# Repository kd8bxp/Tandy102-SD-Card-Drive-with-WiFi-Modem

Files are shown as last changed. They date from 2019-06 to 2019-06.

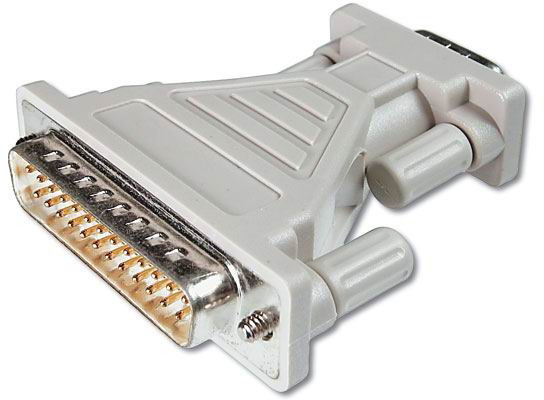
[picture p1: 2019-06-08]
9-to-25-Pin-Serial-Adapter-Pinout.jpg

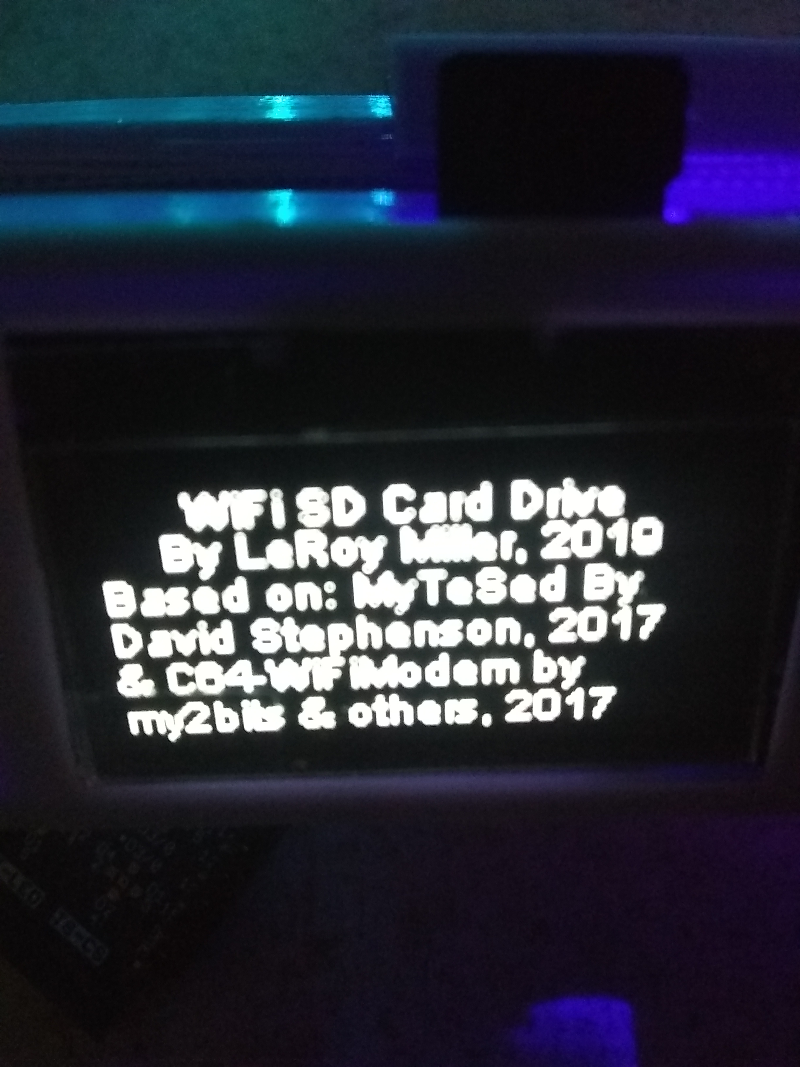
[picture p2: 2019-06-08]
Pictures/IMG_20190527_114814271.jpg

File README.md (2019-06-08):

# Tandy 102 WiFi SD Card

This could not have been made without the following projects:  
 MyTeSed: T100 SD Card Reader for the Arduino Nano and SD Card Reader. By David  
Stephenson 10-11-2017.  
https://www.zx81keyboardadventure.com/2017/08/model-100-micro-sd-card-reader-mytesed.html  
https://youtu.be/7AtsHzl9WMc  
This project "emulates" a PDD - I use emulate loosely. It does let you load and save programs to/from the Tandy 102. It saves the programs to the SD card.  

The next project is the C64-WiFiModem project that was based on serveral other projects.  
The version I used can be found here:  https://github.com/DrZingo/c64-wifimodem  
   C64-WiFiModem - (c) 2017 my2bits <markus at borgelin.org>  
See the credit.h file for more information about this project.  
The basics of it, it gives the ability of vintage machines to connect to the web,  
and is really good for telneting to online BBS systems.  
AT? for help.  

These two projects were ported over to the ESP32, which wasn't that hard to do, a few changes to the base code were needed.  
One thing that stopped working is the ability to telnet into the vintage machine (so for now, you can't run that BBS on your Tandy 102).  

The final project that made all this come together is FTP Server based on FTPServerSample & esp8266FTPServer by nailbuster Oct 2017
https://github.com/nailbuster/esp8266FTPServer
Modified by robo8080 for SD card use 2017 https://github.com/robo8080/ESP32_FTPServer_SD  

The only thing I did was to add some feedback displayed on the OLED, otherwise that project already worked on the ESP32  
 
## Things To Do

After I got all the code working, I just merged the 3 base codes together with a menu system that I wrote, because of this:  
There is some redundant code, and future versions I want to clean it up as much as  
I can.  
Telnet Server doesn't work, I'd like to figure out how to get that working.  
And maybe add code in all the bases to switch from one mode to the next easy. (Maybe)  
The SD card reader needs to have the leading "/" included with file names.  
I'd like to have software check for this an add it if needed.  
Currently, you need it otherwise it doesn't work - there is no error printed so you don't know it doesn't work.  
Interestingly enought you don't need the leading "/" when using FTP, but you do need a good FTP client, at least I did.  

## Hardware Used

1) TTGO T-eight board - this board has an ESP32, on board SD card reader/writer, 3 switch/button toggle, OLED, and lipo charger (I'm not using a battery).  
2) MAX232 board, the board I am using has a 9pin female connector, and only has RX/TX broken out. 5v and Ground  
3) 9 pin to 25 pin serial adaptor for the Tandy, and maybe/probably a 9 pin serial gender changer.  
4) (Optional) 3D printed case and stand.  

Hookup is fairly easy and straight forward, connect the Max232 VCC to 5v pin, GND to GND, TX to TX, and RX to RX, load the sketch on the board, and test.  
IF it doesn't work, try reversing the TX and RX pins (in other words, connect TX to RX, and RX to TX).  

## Usage

My Tandy 102 didn't like an speed but 300 baud, I know slow. So you need to have your com port set for 300 baud. (38N1D works)  
For the SD card drive, in the terminal type "help" without the quotes. You'll get a
small amount of "help" - It's not very good, but might be enough to give you some help.  

For the C64-WiFiModem you can use "AT?" in command mode, and you'll get some help.  

You need a good FTP Client when using the FTP mode.  
(You don't need to remove the SD card, and can copy and move files on the SD card over FTP) - It's nice!   

To get back to the menu, use the center button.  The ESP32 will reset and you'll get the menu again.  

## Demo Video

coming soon....  

## Contributing

1. Fork it!
2. Create your feature branch: `git checkout -b my-new-feature`
3. Commit your changes: `git commit -am 'Add some feature'`
4. Push to the branch: `git push origin my-new-feature`
5. Submit a pull request

## Support Me

If you find this or any of my projects useful or enjoyable please support me.  
Anything I do get goes to buy more parts and make more/better projects.  
https://www.patreon.com/kd8bxp  
https://ko-fi.com/lfmiller  
https://www.paypal.me/KD8BXP  

## Other Projects

https://www.youtube.com/channel/UCP6Vh4hfyJF288MTaRAF36w  
https://kd8bxp.blogspot.com/  

## Credits

Copyright (c) 2019 LeRoy Miller

## License

This program is free software: you can redistribute it and/or modify
    it under the terms of the GNU General Public License as published by
    the Free Software Foundation, either version 3 of the License, or
    (at your option) any later version.

    This program is distributed in the hope that it will be useful,
    but WITHOUT ANY WARRANTY; without even the implied warranty of
    MERCHANTABILITY or FITNESS FOR A PARTICULAR PURPOSE.  See the
    GNU General Public License for more details.

    You should have received a copy of the GNU General Public License
    along with this program.  If not, see <http://www.gnu.org/licenses>

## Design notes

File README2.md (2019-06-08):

## Robot Code

Included is one example of controlling a robot over WiFi with the Tandy 102.  
arexx_d1_mini_telnet_controlled_robot_test_code - this is basicly a telnet server running on a D1 Mini (ESP8266) board, connected to the D1 Mini Motor Shield, using a general/genic 2 wheeled robot plateform.  
In the Tandy102_Robot_Code directory, you'll find the basic program that the Tandy 102 runs - it's pretty simple.  
Turn the SD WiFi card device on, selected the WiFi Modem, run the basic program, which should hit the enter key, connect to the D1 Mini Access Point, and make the robot move forward for a short time, and stop.  
It's just one example of what can be done.

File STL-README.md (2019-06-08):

## Credit where credit is due

The stand was created by Denny77 Dec 2017, https://www.thingiverse.com/thing:2689401  
I made it larger, but otherwise it's his design.  

The lid is my own creation, I'm not very good at making lids yet, but this one works.  

The case is a remix of my TTGO Teight case https://www.thingiverse.com/thing:3634368  
I made it taller, then because the MAX232 board is slightly larger, I stuck a larger box on top (or bottom depending on how you look at it.) This give a interesting two layer effect.  
I ended up cutting the openning for the 9 Pin port a little bit to get the board to fit a little better, and the 9 pin gender changer is used to help hold it in place.  

I took a guess on the size the stand should be, and happy accident it fit almost perfect (honestly it's just slightly too big, but that makes it easy to slide the case in and out).  

So what wasn't planned, turned out to be a good fit for the case.

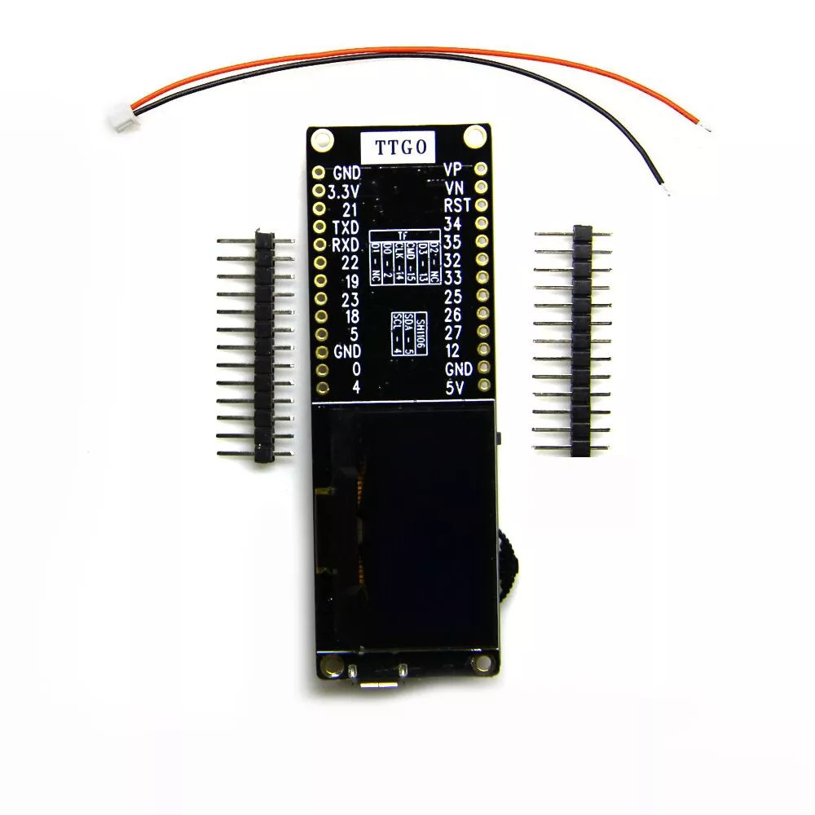
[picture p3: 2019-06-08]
ttgo-teight.jpg

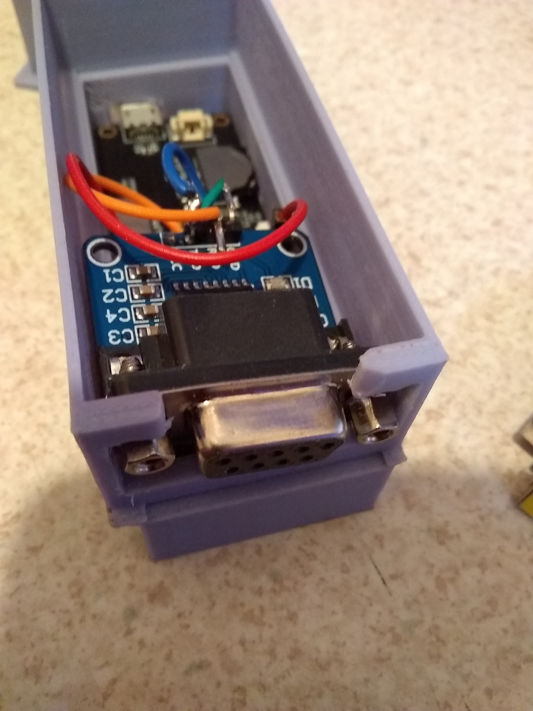
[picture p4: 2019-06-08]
Pictures/2019-06-08 01.26.06.jpg

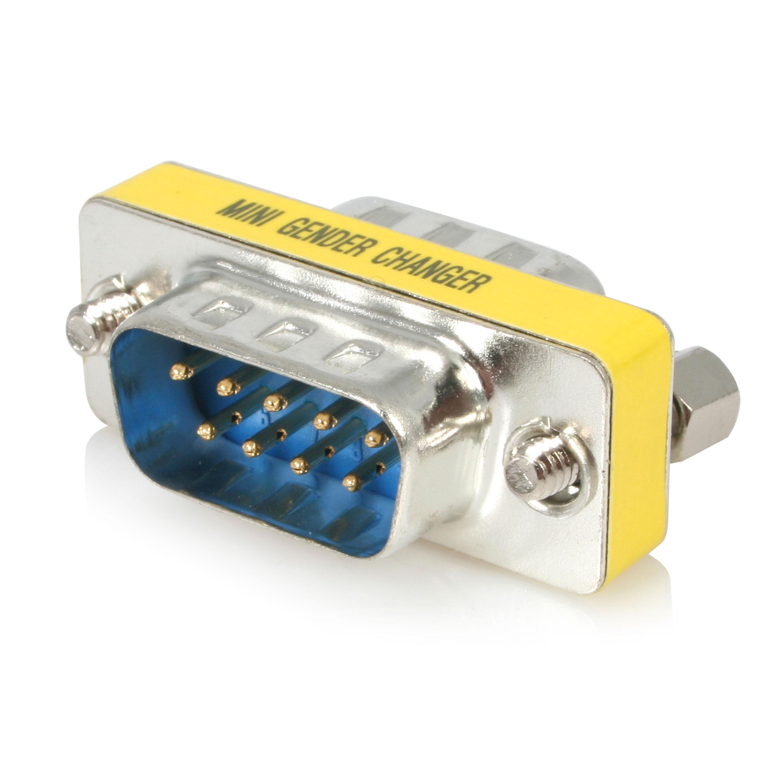
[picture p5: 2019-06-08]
6ada19d5-7ea9-411c-b23a-e80710b06e3e.jpg

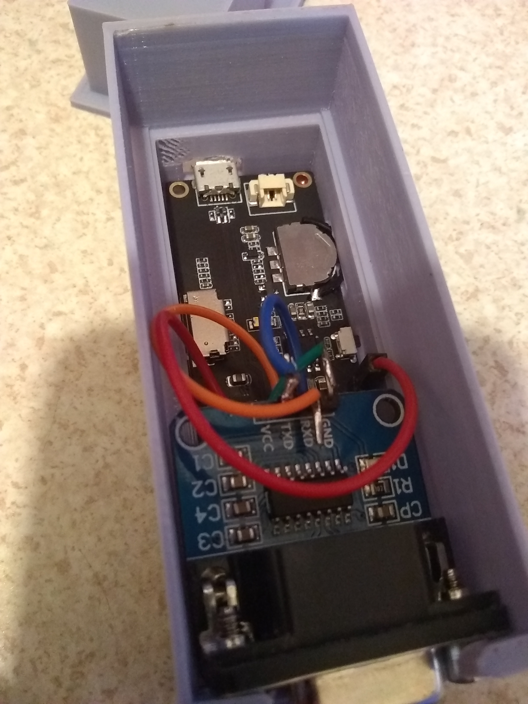
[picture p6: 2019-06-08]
Pictures/2019-06-08 01.26.12.jpg

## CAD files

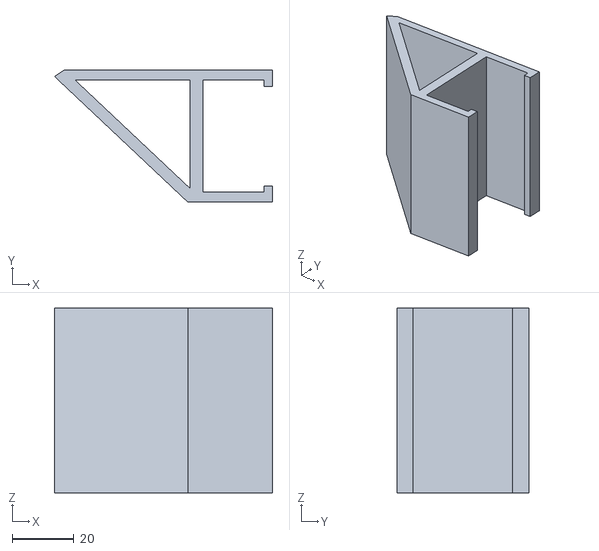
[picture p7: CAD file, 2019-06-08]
STL_Files/stand.stl
70.8 x 43.0 x 60.0

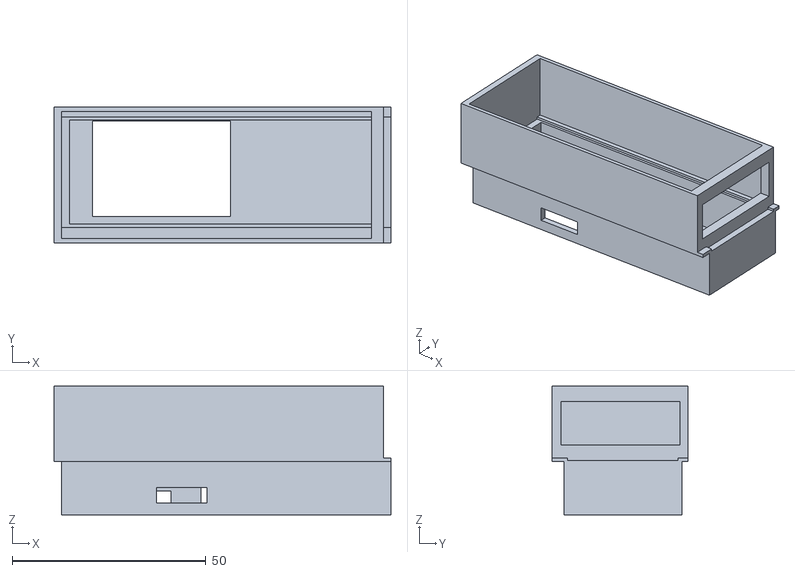
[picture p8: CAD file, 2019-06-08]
STL_Files/case.stl
87.0 x 35.0 x 33.2

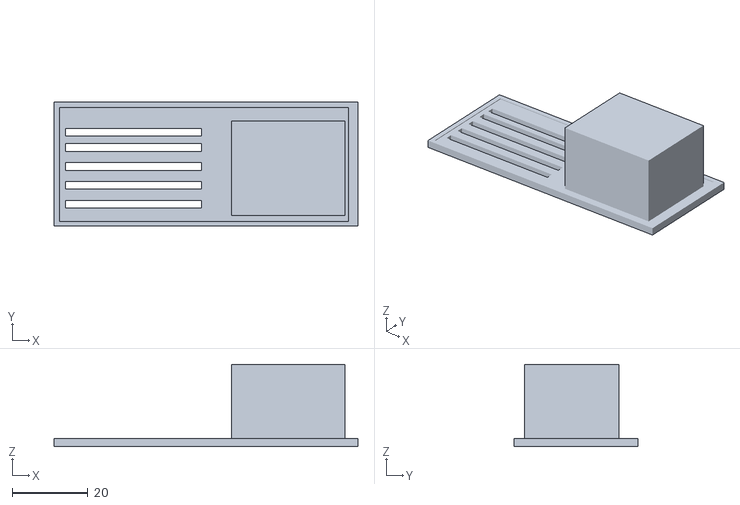
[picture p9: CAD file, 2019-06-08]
STL_Files/Lid.stl
80.2 x 32.7 x 21.8

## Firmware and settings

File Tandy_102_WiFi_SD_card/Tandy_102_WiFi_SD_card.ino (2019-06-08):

/*
 * Tandy 102 WiFi SD card drive
 * Ported to ESP32 by LeRoy Miller May 2019
 * see credit.h tab for additional information and credit to other projects.
 */

#include <SPI.h>
#include <SD.h>
#include "XModem.h" // Xmodem Only working with the NEC PC-8401 at the moment... To be fixed at some point.
#include <Wire.h>  // Only needed for Arduino 1.6.5 and earlier
#include "SH1106Wire.h" // alias for `#include "SSD1306Wire.h"`
#include "SH1106.h" //https://github.com/ThingPulse/esp8266-oled-ssd1306
#include <WiFi.h>
#include <WebServer.h>
#include <EEPROM.h>
#include <ESPmDNS.h>
#include <HTTPClient.h>
#include "defines.h"
#include <WiFiClient.h>
#include "ESP32FtpServer.h"

const char* FTPssid = "homeinternet"; //for now this is how we are going to connect using the FTP server
const char* FTPpassword = "trixie4me"; //I want to change this to make the code more lean.

FtpServer ftpSrv;   //set #define FTP_DEBUG in ESP32FtpServer.h to see ftp verbose on serial


SH1106 display(0x3c, 21, 22); 
WiFiClient tcpClient;
WiFiServer tcpServer(tcpServerPort);
WebServer webServer(80);
MDNSResponder mdns;


// **** Setup Constants ****

// Set default Baud Rate
// Settings on T100/T02/T200 for reference
// 1 = 75,   2 = 110,  3 = 300
// 4 = 600,  5 = 1200, 6 = 2400
// 7 = 4800, 8 = 9600, 9 = 19200
//const int BAUD_RATE=19200; // Tandy T100/T02/T200
//const int BAUD_RATE=9600; // NEC PC-8401
const int BAUD_RATE=300;

// Write out Delay
// Without Hardware flow control all writing to the T100 requires a delay
// This allows for fast saving and a normal loading speed
// This ends up reducing the T100 inbound baud rate to aprox 2400 from 19200
// Writing to the Screen in Telcom from SD requires 2*the OUT_DELAY
const byte OUT_DELAY=10;

// Commands issued to MyTeSeD
// LOAD:  Load directly from SD card into BASIC
// SAVE:  Save BASIC File directly to SD card
// KILL:  Delete file from SD card
// MOVE:  Rename File on SD card
// TCOPY: Copy from SD card to T100
// MCOPY: from T100 to SD
// ERR:   Return last Error code.
const String KEYWORDS[12] = {"LOAD","SAVE","FILES","KILL","HELP","DEL","DIR","COPY2R","COPY2D","CAT","XGET"};

// Set Serial Port Modes
// FREE:     Not busy
// DATA_IN:  Reading From T100
// DATA_OUT: Sending to T100
enum SerialStates {FREE, DATA_IN, DATA_OUT};

// Command Time Out: If no data from T100 after 15 seconds timeout on "SAVE" or "COPY2D"
const long TIMEOUT = 15000;

// Character Codes
// LF = Line Feed, CR = carriage return, EF = End of File
//enum CharCodes {LF = 10, CR = 13, EF = 26};

// ** LF & CR in XModem.h
// #define LF 0x0a
// #define CR 0x0d
#define EF 0x1a

// Error Codes
// Same values as T100
// SN = Syntax Error
// FF = File Not Found
// NM = Bad File Name
// CF = File Not Open (SD Card Not Found)
// Values could be sent to T100 for standard feed back with 'Error X' command
enum ErrorCodes {OK1 = 0, SN = 2 , FF = 52, NM = 55, CF = 58};

// Define Xmodem
XModem MyXmodem(&Serial, ModeXModem);

// **** Define Classes ****


// ***********************************************
// * Read / Writ SD Card send Serial out to T100 *
// ***********************************************
class SDCardDrive {

	private:

	// Variable for Saving Files
	File InFile; // File to save to

	ErrorCodes FileOut(String sFileName, byte bDelayOutLevel = 0){

		ErrorCodes eError = OK1;

		File OutFile;
		char cRead, cLast, cCount=1;
display.clear();
display.drawString(0,0,"Load...");
display.drawString(45,0,sFileName);
display.display();

		delay(250);
		OutFile = SD.open(sFileName);

		if(!OutFile){
			eError = FF;
		} else {
			// If bDelayOutLevel multiplier greater than 1
			// Then we are (willingly) writing to the LCD Screen
			// Add a LF for easy reading
			if(bDelayOutLevel > 1){
				Serial.write(CR);
				Serial.write(LF);
				delay(OUT_DELAY*(bDelayOutLevel*2));
			}

			while(OutFile.available()){
				if ( cCount == 2 ){
					delay(OUT_DELAY*bDelayOutLevel);
      				cCount = 1;
				}
				cCount++;
				cRead=OutFile.read();

				// If This is a BASIC file 'LOAD' ensures CR formating is used
				// Else outputs text as is
				if (cRead == LF && cLast != CR ){
					//Serial.write(cRead);
					Serial.write(CR);
        
				}

				Serial.write(cRead);
				cLast = cRead;
        
			}
		}

		OutFile.close();
    display.drawString(0,10,"Done!");
    display.display();
    
		// Only Write EOF of not writing to LCD
		if(bDelayOutLevel <= 1) Serial.write(EF);
		Serial.flush();

		return eError;

	}

	ErrorCodes FileOutXmodem(String sFileName){
		ErrorCodes eError = OK1;

		File OutFile;
		OutFile = SD.open(sFileName);

		// Make OLED displaySerial.println("Xmodem ready");
   display.clear();
   display.drawString(0,0,"Xmodem Ready.");
   display.display();
		if(!OutFile){
			eError = FF;
		} else {
			// Convert to sFileName to CPP style string
			// Make OLED displaySerial.println("Xmodem Sending");
     display.drawString(0,10,"Xmodem Sending.");
     display.display();
			//MyXmodem.sendFile(OutFile, sFileName.c_str());
      char buffer[15];
      sFileName.toCharArray(buffer, 15);
      MyXmodem.sendFile(OutFile, buffer);
      //MyXmodem.sendFile(OutFile, "testme.ba");
		}

		OutFile.close();
		return eError;
	}

	ErrorCodes FileInDelete(String sFileName, byte bDelayOutLevel = 0){
		ErrorCodes eError = OK1;
		if (SD.exists(sFileName)) {
			SD.remove(sFileName);
		} else {
			eError = FF;
		}
		// Assume for 'DEL' command we are writing to the LCD
		if(bDelayOutLevel > 0){
			Serial.write(CR);
			Serial.write(LF);
			delay(OUT_DELAY*(bDelayOutLevel*2));
		}
	}

	ErrorCodes FileInOpen(String sFileName){
		ErrorCodes eError = OK1;

		FileInDelete(sFileName);

		InFile = SD.open(sFileName, FILE_WRITE);

		if(!InFile){
			InFile.close();
			eError = FF;
		}

		return eError;
	}

	ErrorCodes FileDirOut(byte bDelayOutLevel = 4){

		ErrorCodes eError = OK1;

		File DirFile = SD.open("/");
		File FileInfo;

		if(!DirFile){
			eError = FF;
		} else {

			Serial.write(CR);
			Serial.write(LF);
			delay(OUT_DELAY*(bDelayOutLevel*4));

			//DirFile.rewindDirectory();

			while (true) {
				FileInfo = DirFile.openNextFile();

				if(!FileInfo){
					// no more files
					break;
				} else {
					//if (!FileInfo.isDirectory() && strlen(FileInfo.name()) < 10)  {

						// Only list files with a 2 character extension
						//if(FileInfo.name()[strlen(FileInfo.name())-3] == '.'){

							Serial.write(FileInfo.name());
              Serial.print("\t\t");
              Serial.println(FileInfo.size(), DEC);
							//Serial.write(FileInfo.name());
							delay(OUT_DELAY*bDelayOutLevel);

							/*for (byte iCount = strlen(FileInfo.name()) ; iCount < 10 ; iCount++){
								Serial.write(32);
								Serial.write(32);
							}*/

							delay(OUT_DELAY*bDelayOutLevel);

						//}

					//}
				}

				FileInfo.close();
			}

			Serial.write(CR);
			Serial.write(LF);
			delay(OUT_DELAY*bDelayOutLevel);

		}

		DirFile.close();
		//Serial.write(EF);
		Serial.flush();

		return eError;

	}


	// Return true if file is open
	boolean FileInWrite(char cInChar) {
  display.clear();
  display.drawString(0,0,"Saving....");
  display.display();
		if(cInChar != EF){
			Serial.print(cInChar);
			InFile.print(cInChar);
			return true;
		} else {
			InFile.close();
     display.drawString(0,10,"Done.");
     display.display();
			return false;
		}

	}


	public:

	// Open and read file
	// bBasicFile needs to be true if loading or saving a 'BASIC' file directly
	ErrorCodes ReadFile(String sFileName, byte bDelayOutLevel = 1){
		// Open SD card reader
		return FileOut(sFileName, bDelayOutLevel);
	}

	ErrorCodes ReadFilesDir(byte bDelayOutLevel = 8){
		// Open SD card reader
		return FileDirOut(bDelayOutLevel);
	}

	ErrorCodes FileXGet(String sFileName){
		return FileOutXmodem(sFileName);
	}

	ErrorCodes FileDelete(String sFileName,byte bDelayOutLevel = 1){
		// Open SD card reader
		return FileInDelete(sFileName, bDelayOutLevel);
	}

	ErrorCodes OpenFile(String sFileName){
		// Open SD card reader
		return FileInOpen(sFileName);
	}

	boolean OutFile(char cInChar){
		return FileInWrite(cInChar);
	}

	void OutFileTimeOut(){
    display.clear();
    display.drawString(0,0,"Timeout: File Closed");
    display.display();
		InFile.close();
	}
 
};


// *************************************
// * User Command from Serial in / out *
// *************************************
class SerialInOut {

	private:

	ErrorCodes eLastError;

	SDCardDrive InOutSD;
	SerialStates eComState = FREE;
	String sInString;

	// Track Command In
	unsigned long iUpdateLast = 0;

	// Simple filename check: Filename valid on a T100
	// Filename must hav and extension
	// Filename should only be up to 6 CHAR with 2 CHAR extension with '.' separator
	// bBasicFile needs to be true if loading or saving a 'BASIC' file directly
	ErrorCodes CheckFileName(boolean bBasicFile = false){
		String sExtension;
		// Check filename length withn 6 CHAR
		if(sInString.indexOf('.') < 8 && sInString.indexOf('.') == sInString.lastIndexOf('.')){
			// Check filename extension is 2 CHAR
			if(sInString.length()-sInString.indexOf('.')-1 == 2){
				sExtension = sInString.substring(sInString.indexOf('.')+1,sInString.length());
				// if checking and LOADING a file to BASIC allow extension BA and DO
				if(bBasicFile == false || (bBasicFile == true && (sExtension == "BA" || sExtension == "DO"))){
					return OK1;
				}
			}
		}
		return NM;
	}

	ErrorCodes GetCommand(){

		ErrorCodes eError = OK1;

		
		sInString.toUpperCase();
    sInString.trim();

		// Cycle through KEYWORDS for matching command
		for (int bKeyword = 0 ; bKeyword < 12 ; bKeyword++){
			if(sInString.length() >= KEYWORDS[bKeyword].length()){
				if (sInString.startsWith(KEYWORDS[bKeyword])){
					// Trim Command from String
					sInString = sInString.substring(KEYWORDS[bKeyword].length());
					sInString.trim();
					// If Command found and we need an ARG such as a filename
					if (sInString.length() != 0 || KEYWORDS[bKeyword] == "DIR" || KEYWORDS[bKeyword] == "FILES" || KEYWORDS[bKeyword] == "HELP"){

						// ********************************
						// * Select Output to M100 / M102 *
						// ********************************

						if (KEYWORDS[bKeyword] == "LOAD"){
							// Flag as loading direct to BASIC
							eError = CheckFileName(true);
							if(eError==OK1){
								eError = InOutSD.ReadFile(sInString);
							}

							break;
						}

						// Send direct to a RAM file or LCD screen
						else if (KEYWORDS[bKeyword] == "COPY2R" || KEYWORDS[bKeyword] == "CAT"){
							
                 char cRead, cLast;
                 File MyFile = SD.open(sInString);
                 display.clear();
                 display.drawString(0,0,"Load/CAT...");
                 display.drawString(58,0,sInString);
                 display.display();
                 if (MyFile) {
                  while(MyFile.available()){
                    cRead=MyFile.read();
                    if (cRead == LF) {
                      if (cLast != CR); {
                      Serial.write(CR);
                      
                    }
                    Serial.write(LF);
                  } else {
                    Serial.write(cRead);
                    cLast=cRead;
                  }
                 }
                 }
                 MyFile.close();
                 display.drawString(0,10,"Done!");
                 display.display();
                 Serial.write(EF);
								break;
						}

						else if (KEYWORDS[bKeyword] == "XGET"){
							eError = CheckFileName(false);
							if(eError==OK1){
								eError = InOutSD.FileXGet(sInString);
							}
							break;
						}


						else if (KEYWORDS[bKeyword] == "DIR" || KEYWORDS[bKeyword] == "FILES"){

							eError = InOutSD.ReadFilesDir();
							break;
						}

						else if (KEYWORDS[bKeyword] == "DEL" || KEYWORDS[bKeyword] == "KILL"){
							eError = CheckFileName(false);
							if(eError==OK1){
								eError = InOutSD.FileDelete(sInString,2);
							}
							break;
						}

						// *********************************
						// * Select Input from M100 / M102 *
						// *********************************

						else if (KEYWORDS[bKeyword] == "SAVE") {
							// Check Filename
							eError = CheckFileName(true);
							if(eError==OK1) eError = InOutSD.OpenFile(sInString);
							// Once SD card is opened
							if(eError==OK1) {
								eComState = DATA_IN;
							}

							break;
						}

						else if (KEYWORDS[bKeyword] == "COPY2D") {
							// Check Filename
							eError = CheckFileName(false);
							if(eError==OK1) eError = InOutSD.OpenFile(sInString);
							// Once SD card is opened
							if(eError==OK1) {
								eComState = DATA_IN;
							}

							break;
						}

           else if (KEYWORDS[bKeyword] == "HELP") {
            //Serial.println("LOAD,SAVE,DEL,DIR,COPY2R,COPY2D,CAT,XGET,FILES,KILL,HELP");
            display.clear();
            display.drawString(0,0,"LOAD, SAVE, DEL, DIR,");
            display.drawString(0,9,"COPY2R, COPY2D, CAT,");
            display.drawString(0,18,"XGET, FILES, KILL");
            display.display();
            eComState = FREE;
            break;
           }
          
						//string.startsWith(string2)
					}
				}
			}
		}

		if(eComState != DATA_IN) eComState = FREE;
		sInString = "";
		return eError;
	}

	public:

	void NoDataIn(){

		unsigned long iUpdateTime = millis();

		// Check last DATA_IN Command hasn't timed out, if so close it
		if (iUpdateTime - iUpdateLast >= TIMEOUT && eComState == DATA_IN) {
			InOutSD.OutFileTimeOut();
			eComState = FREE;
		}

	}

	void SerialIn(char cInChar){

		boolean WriteFileOpen;

		iUpdateLast = millis();

		switch(eComState) {
			case FREE:
				if(cInChar == CR){
					// Set to send data from T100 on Command in
					eComState = DATA_OUT;
					eLastError = GetCommand();
				} else {
					sInString += cInChar;
				}
				break;
			case DATA_IN:
					WriteFileOpen = InOutSD.OutFile(cInChar);
					if (WriteFileOpen == false) eComState = FREE;
				break;
		}
	}

};

// **** Global Variables  / Classes ****
SerialInOut InOut;


void setup() {
  Serial.begin(BAUD_RATE);

  pinMode(UP, INPUT);
pinMode(BUTTON, INPUT);
pinMode(DOWN, INPUT);
  display.init();
display.setFont(ArialMT_Plain_10);
 display.drawString(5, 0, "Tandy 102 WiFi SD card");
 
display.drawString(16,9,"LeRoy Miller, 2019");
display.drawString(0,19,"Based on: MyTeSed By");
display.drawString(0,29,"David Stephenson, 2017");
display.drawString(8,39,"C64-WiFiModem by");
display.drawString(0,49,"my2bits & others, 2017");
display.display();
delay(8000);
display.clear();
display.drawString(5, 0, "Tandy 102 WiFi SD card");
display.drawString(0,10, "FTP Server by nailbuster");
display.drawString(10,20, "& robo8080, 2017");
display.drawString(17,35, "Menu Code by");
display.drawString(5,45, "LeRoy Miller, 2019");
display.display();
delay(8000);
display.clear();
menuLevel = startMenuLevel;

/*if(!SD.begin(5)){
  //OLED Display Card Ready/Not Ready
    //Serial.println("SD Card Not Found");
    display.drawString(0,0,"SD Card Not Found.");
    display.drawString(0,50,"Power OFF before inserting card.");
    display.display();
    delay(5000);
    ESP.restart();
  } else {
    //Serial.println("SD Card Found");
    display.drawString(0,0,"Ready.");
    display.display();
  }*/
}

void loop() {
  
  display.clear();
  drawMenu();
  

while(digitalRead(BUTTON) != LOW) {
  if (menuLevel == 1) { 
    display.clear();
    drawMenu();
    display.drawString(0, 24, ">");
    //display.drawString(0, 22, "");
    //display.drawString(0, 33, "*");
  }
  if (menuLevel == 2) {
    display.clear();
    drawMenu();
    //display.drawString(0,12, "*");
    display.drawString(0,34, ">");
    //display.drawString(0,33, "*");
  }
  if (menuLevel == 3) {
    display.clear();
    drawMenu();
    //display.drawString(0,12, "*");
    //display.drawString(0,22, "*");
    display.drawString(0,44, ">");
  }
  
  display.display();
  if (digitalRead(UP) == LOW) {
    if (menuLevel < maxMenuLevel) { menuLevel++; }
    else {menuLevel = maxMenuLevel;}
  }
  if (digitalRead(DOWN) == LOW) {
    if (menuLevel > 1) { menuLevel--; }
    else { menuLevel = 1; }
  }
  delay(100);
}

display.clear();
switch(menuLevel) {
  case 1:
  SDsetup();
  break;
  case 2:
  modemSetup();
  break;
  case 3:  
  FTPsetup();
  break;
  default:
  break;
}
display.clear();
display.setFont(ArialMT_Plain_10);
display.drawString(0,0,"Restarting in 5 seconds.");
display.display();
delay(5000);
ESP.restart();
}

void drawMenu() {
  //display.clear();
  display.drawString(5, 0, "Tandy 102 WiFi SD card");
  display.drawString(35,10,"Main Menu!");
  display.drawString(12, 24, "SD Card Storage");
  display.drawString(12, 34, "WiFi Modem");
  display.drawString(12, 44, "FTP Server");
  
  //display.display();
}

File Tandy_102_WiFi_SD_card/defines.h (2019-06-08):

// Mostly from C64-WiFiModem and global variables

#define VERSIONA 0
#define VERSIONB 1
#define VERSION_ADDRESS 0    // EEPROM address
#define VERSION_LEN     2    // Length in bytes
#define SSID_ADDRESS    2
#define SSID_LEN        32
#define PASS_ADDRESS    34
#define PASS_LEN        63
#define IP_TYPE_ADDRESS 97   // for future use
#define STATIC_IP_ADDRESS 98 // length 4, for future use
#define STATIC_GW       102  // length 4, for future use
#define STATIC_DNS      106  // length 4, for future use
#define STATIC_MASK     110  // length 4, for future use
#define BAUD_ADDRESS    111
#define ECHO_ADDRESS    112
#define SERVER_PORT_ADDRESS 113 // 2 bytes
#define AUTO_ANSWER_ADDRESS 115 // 1 byte
#define TELNET_ADDRESS  116     // 1 byte
#define VERBOSE_ADDRESS 117
#define PET_TRANSLATE_ADDRESS 118
#define FLOW_CONTROL_ADDRESS 119
#define PIN_POLARITY_ADDRESS 120
#define DIAL0_ADDRESS   200
#define DIAL1_ADDRESS   250
#define DIAL2_ADDRESS   300
#define DIAL3_ADDRESS   350
#define DIAL4_ADDRESS   400
#define DIAL5_ADDRESS   450
#define DIAL6_ADDRESS   500
#define DIAL7_ADDRESS   550
#define DIAL8_ADDRESS   600
#define DIAL9_ADDRESS   650
#define BUSY_MSG_ADDRESS 700
#define BUSY_MSG_LEN    80
#define LAST_ADDRESS    780

// Telnet codes
#define DO 0xfd
#define WONT 0xfc
#define WILL 0xfb
#define DONT 0xfe
#define UP 37
#define BUTTON 38
#define DOWN 39

// Global variables
String build = "9";
String firmwareVersion =  "C64-wifimodem-" +  String(VERSIONA) + "." + String(VERSIONB) + "." + build;
String cmd = "";           // Gather a new AT command to this string from serial
bool cmdMode = true;       // Are we in AT command mode or connected mode
bool callConnected = false;// Are we currently in a call
bool telnet = false;       // Is telnet control code handling enabled
bool verboseResults = false;
//#define DEBUG 1          // Print additional debug information to serial channel
#undef DEBUG
#define LISTEN_PORT 6400   // Listen to this if not connected. Set to zero to disable.
int tcpServerPort = LISTEN_PORT;
#define RING_INTERVAL 3000 // How often to print RING when having a new incoming connection (ms)
unsigned long lastRingMs = 0; // Time of last "RING" message (millis())
//long myBps;                // What is the current BPS setting
#define MAX_CMD_LENGTH 128 // Maximum length for AT command
char plusCount = 0;        // Go to AT mode at "+++" sequence, that has to be counted
unsigned long plusTime = 0;// When did we last receive a "+++" sequence
#define LED_TIME 15         // How many ms to keep LED on at activity
unsigned long ledTime = 0;
#define TX_BUF_SIZE 256    // Buffer where to read from serial before writing to TCP
// (that direction is very blocking by the ESP TCP stack,
// so we can't do one byte a time.)
uint8_t txBuf[TX_BUF_SIZE];
const int speedDialAddresses[] = { DIAL0_ADDRESS, DIAL1_ADDRESS, DIAL2_ADDRESS, DIAL3_ADDRESS, DIAL4_ADDRESS, DIAL5_ADDRESS, DIAL6_ADDRESS, DIAL7_ADDRESS, DIAL8_ADDRESS, DIAL9_ADDRESS };
String speedDials[10];
const long bauds[] = { 300, 1200, 2400, 4800, 9600, 19200, 38400 }; // not needed yet  57600, 115200
byte serialspeed;
bool echo = true;
bool autoAnswer = false;
String ssid, password, busyMsg;
byte ringCount = 0;
String resultCodes[] = { "OK", "CONNECT", "RING", "NO CARRIER", "ERROR", "", "NO DIALTONE", "BUSY", "NO ANSWER" };
enum resultCodes_t { R1_OK, R1_CONNECT, R1_RING, R1_NOCARRIER, R1_ERROR, R1_NONE, R1_NODIALTONE, R1_BUSY, R1_NOANSWER };
unsigned long connectTime = 0;
bool petTranslate = false; // Fix PET MCTerm 1.26C Pet->ASCII encoding to actual ASCII
bool hex = false;
enum flowControl_t { F_NONE, F_HARDWARE, F_SOFTWARE };
byte flowControl = F_NONE;      // Use flow control
bool txPaused = false;          // Has flow control asked us to pause?
enum pinPolarity_t { P_CBM, P_NORMAL }; // Is LOW (0) or HIGH (1) active?
byte pinPolarity = P_CBM;

//used for menu system
int maxMenuLevel = 3;
int startMenuLevel = 1;
int menuLevel;
